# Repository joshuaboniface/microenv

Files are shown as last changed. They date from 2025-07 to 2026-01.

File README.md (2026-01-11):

# MicroEnv v2.x

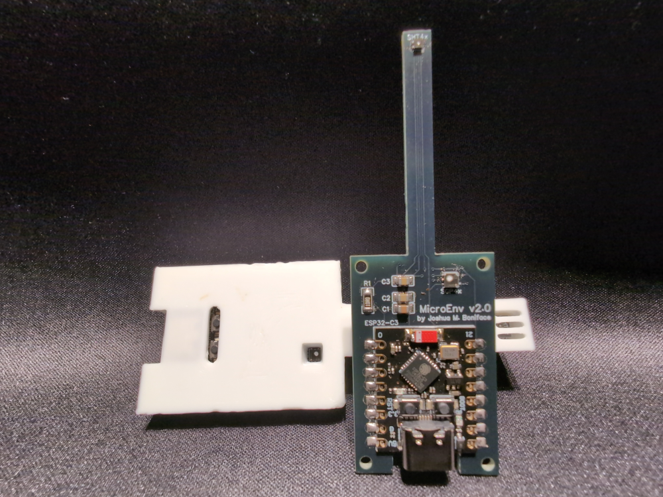
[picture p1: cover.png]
MicroEnv


The MicroEnv is a compact and simplistic environmental monitoring sensor, based on the ESP32-C3 and the Sensirion SGP41 VOC/NOx and SHT45 temperature/humidity sensors, using ESPHome for integration with HomeAssistant.

Use a MicroEnv near a source of emissions to monitor air quality, evaluate temperatures, or as a general room environmental tracking sensor. It is, in effect, a cut down version of the environmental sensor package of my [SuperSensor](https://github.com/joshuaboniface/supersensor) project in a standalone footprint designed for maximum temperature accuracy.

Power is provided by USB-C, which is also used for initial flashing. Once running, the device connects to WiFi to provide data to Home Assistant or via the ESPHome WebUI/API.

The Sensirion sensors are directly soldered onto the board along with their power management circuitry, using SMD techniques, which is in contrast to the socketed GY-form-factor sensors from [version 1.x](https://github.com/joshuaboniface/microenv/tree/v1.x). This provides more compactness and flexibility in terms of positioning to ensure the temperature sensor is properly isolated from the rest of the system.

Version 2.x features an extended 5mm-width, 40mm-length "neck", the end of which contains the SHT45 temperature sensor, for maximum isolation from the ESP32 and SGP41 sensor, both of which produce heat which can negatively affect the SHT45 temperature. This emulates the design of many temperature probe devices which use similar long boards for isolation purposes and work quite well in this regard.

MicroEnv Board Design

The PCB design details and assembly instructions can be found [in /board](board/) and on [OSHWLab](https://oshwlab.com/joshuaboniface/microenv-2-0).

Since this revision uses directly SMD-mounted components, it requires fine soldering using solder paste and either a hotplate or, with extreme care, hot air soldering techniques. It is strongly recommended that anyone attempting to build one read the datasheets for the [SHT45](https://sensirion.com/media/documents/33FD6951/67EB9032/HT_DS_Datasheet_SHT4x_5.pdf) and [SGP41](https://sensirion.com/media/documents/5FE8673C/61E96F50/Sensirion_Gas_Sensors_Datasheet_SGP41.pdf) sensors thoroughly to ensure they are not subject to overheating which can result in potential damage or incorrect operation. We recommend using low-temperature GA-SN solder paste for this purpose, and suggest ordering the PCB with lead-free HASL to facilitate this.

## v1.x Compatibility

The only changes between v1.x and v2.x are in the board layout and component mounting; for software purposes, both versions are functionally identical aside from versioning. Thus all changes should be ported to both the `v1.x` and `v2.x` branches. There is no `master` branch.

## Parts List

**Note:** All prices are $CAD, as of late November 2025, excluding shipping, sales, and bulk discounts beyond those indicated.

**Note:** For AliExpress item links marked `*`, ensure you select the correct device; multiple different models share the page.

| Qty | PCB ID(s) | Component | Cost | Links |
|---|---|---|---|---|
| 1 | N/A | PCB - "MicroEnv" | $0.64 ($3.20/5) | [EasyEDA/JLCPCB](/board/pcb.easyeda.json) |
| 1 | ESP32-C3  | ESP32-C3 development board (SMD) | $2.46 ($12.28/5) | [AliExpress](https://www.aliexpress.com/item/1005007205044247.html)*  |
| 1 | SHT4x | Sensirion SHT45-AD1F-R2 | $9.37 | [DigiKey.ca](https://www.digikey.ca/en/products/detail/sensirion-ag/SHT45-AD1F-R2/17180856) |
| 1 | SGP4x | Sensirion SGP41-D-R4 | $13.00 | [DigiKey.ca](https://www.digikey.ca/en/products/detail/sensirion-ag/SGP41-D-R4/15652788) |
| 1 | R1 | CR1206-FX-10R0ELFCT-ND (10Ω 1% 1/4W 1206) | $0.16 | [DigiKey.ca](https://www.digikey.ca/en/products/detail/bourns-inc/CR1206-FX-10R0ELF/2562695) |
| 1 | C1 | 399-C0805C106K8PACTUCT-ND (10μF 10V X5R 0805)  | $0.19 | [DigiKey.ca](https://www.digikey.ca/en/products/detail/kemet/C0805C106K8PACTU/1090830) |
| 1 | C2 | 399-C0805C104K5RACTUCT-ND (0.1μF 50V X7R 0805) | $0.12 | [DigiKey.ca](https://www.digikey.ca/en/products/detail/kemet/C0805C104K5RACTU/411169) |
| 1 | C3 | 399-C0805C105K3RACTUCT-ND (1μF 50V X7R 0805) | $0.18 | [DigiKey.ca](https://www.digikey.ca/en/products/detail/kemet/C0805C105K3RACTU/2211765) |
| **T** | | | **$26.14** | *plus tools, solder, etc.* |

## Case

The MicroEnv design includes [a case to enclose the sensor](case/) while still providing good airflow to cool the microcontroller and provide quality exposure for the sensors. This case can be printed in any material, though ABS is recommended for rigidity and strength.

## Calibration

Due to its design explicitly focusing on temperature accuracy, the MicroEnv should not require any Temperature Offset corrections in normal use; the option is however still provided just in case this is required in your environment.

The heater component of the SHT45 is explicitly disabled, as this should only be required in extreme humidity conditions.

Like its parent SuperSensor, the MicroEnv provides several additional configurable options for a "Room Health" metric system. For more detail, see [the main SuperSensor README](https://github.com/joshuaboniface/supersensor/tree/v3.x/configuration#room-health) section on the Room Health system.

# Contributing

If you wish to contribute to the MicroEnv project, please open a pull request in this repository. All pull requests will be carefully reviewed before inclusion, as we are extremely selective about what we modify. Note that any signifiant logical changes should also be compatible with the SuperSensor, and changes from that project will be occasionally integrated here.

Please ensure you target the correct branch(es) for your changes. Currently we are supporting both `v1.x` and `v2.x` in software as noted above, and there is no `master`/`main` branch. This support of both `v1.x` and `v2.x` means a 1-to-1 correlation of functionality between those two versions, so any PR to one will be back- or forward-ported to the other, and your changes(s) must be compatable with both.

Any changes must be **globally applicable to all users** of the project; if you wish to maintain your own customizations that are only applicable for yourself, please fork the project and adjust your package import URL accordingly.

"AI" (LLM) contributions are not prohibited, but you - a human - **must** at least review, reformat, and test the changes yourself before submitting them. Obviously pure-LLM-generated PRs that do not function, mangle formatting or functionality, or otherwise clearly have no human review will be rejected with prejudice. This extends to the PR body itself: write in your own words, not the output of an LLM, and if you can't concisely sumarize the changes yourself, then we're not interested in them.

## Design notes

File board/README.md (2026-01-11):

# MicroEnv v2.x Board Designs

This is a collection of [EasyEDA](https://easyeda.com/) schematics and board desgins for the MicroEnv v2.x's components.

You can import the design definition files (`*.easyeda.json`) directly into EasyEDA via "File" -> "Open" -> "EasyEDA". The schematic is provided for reference in both EasyEDA and SVG formats; if you just wish to manufacture the boards, you only need to import the board definitions, then via "Fabrication" -> "One-click Order PCB/SMT" complete the order at [JLCPCB](https://jlcpcb.com). We order all boards in a black silkscreen with all other options as default.

You can also see the designs directly on [OSHWLab here](https://oshwlab.com/joshuaboniface/microenv-2-0).

The board design and images in this folder are © 2026 [Joshua M. Boniface](https://www.boniface.me) and licensed under the [Creative Commons Attribution-ShareAlike (BY-SA) 4.0](LICENSE) license.

## Schematic

The schematic is visible here in SVG format, and also as an EasyEDA definition in [schematic.easyeda.json](schematic.easyeda.json).

Design schematic

The individual parts can be found, with their labels (`R1`, etc.) in the [main README parts list](https://github.com/joshuaboniface/microenv/tree/v2.x?tab=readme-ov-file#parts-list).

## Board

MicroEnv v2.x board

This is the main board of the MicroEnv which contains all components, with the SHT45 sensor on a long (40mm) "neck" to isolate it from the other components.

The board is single-sided; there are no components on the reverse side.

## Assembly

Assembly can be accomplished either by hot-air reflow, or with a hotplate. The instructions are functionally identical for both except for the heating step (#5).

The hot-air process requires the least tools, but is finicky and error-prone. The hotplate process is much simpler and more forgiving, but requires a suitable hotplate. We recommend using the hotplate method for any more than a very small number of MicroEnv sensors.

1. Clean all PCBs thoroughly with isopropyl alcohol and paper towel.

2. Carefully apply solder paste to each pad, with the following guidelines:

   * SHT45/SGP41: A very small amount on each pad, including the center pads; if you think it's not enough, it's just right.
   * Passive SMD components (R1, C1-3): A moderate amount on each pad focusing on the outer edges.
   * ESP32-C3: A very liberal amount on each pad for mechanical stability.

3. Place each component on its corresponding pad using tweezers. Ensure the components are properly aligned and then gently press them down into the solder paste.

   **NOTE**: Placing each component after its corresponding solder paste can avoid accidental smudging.

4. Heat the hot air station to 240C; no higher! Apply heat to the **bottom** of the PCB until all the solder reflows. Check carefully for any bridges or failed joins and gently reflow in the same way as necessary. **Never apply heat directly to the sensors themselves!**

5. Perform electrical continuity tests to ensure there are no stray bridges.

The MicroEnv is now fully assembled and ready for final testing/provisioning.

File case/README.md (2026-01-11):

# MicroEnv v2.x Case

This is a 3D-printable case/enclosure for the MicroEnv v2.0 module. This case optional for functionality, but provides excellent aesthetics and a good mounting point for the sensor.

The design features two individual parts:

* A bottom piece which holds the circuit board.
* A top piece which covers the circuit board and sensors, with ample clearance for the components, a USB cable, and airflow for the sensors.

You can [tinker the design on TinkerCAD here](https://www.tinkercad.com/things/irFmvsATUlu-microenv-sensor-v2x-case).

The case design and images in this folder are © 2026 [Joshua M. Boniface](https://www.boniface.me) and licensed under the [Creative Commons Attribution-ShareAlike (BY-SA) 4.0](LICENSE) license.

## Printing

In this directory are 2 `.obj`-format CAD files providing the case. They should be compatible as-is with any slicing software and 3D printer model; no rotation or other transformations are required.

As a general set of parameters, all models should be printed with the following. All values are provided as their OrcaSlicer 2.3 names; your slicer may differ.

* 0.4mm nozzle/line width (or similar as provided by the slicer)
* 0.16mm layer height, or a clean multiple thereof
* No brim or raft
* 7-10 wall loops
* 7-10 shell layers (top + bottom)
* 25% infill
* Concentric patterns for infill
* Concentric patterns for surfaces (visual only)
* Back (preferred) or Aligned seams (visual only)

All other options are be specific to your printer, material, and desired effect.

The parts should be printed in a solid, durable material of any colour you wish. We use ABS in one of two colours (black or white) for our official prints.

### Case Models

These are the models that make up the case. Each case requires 1x `case-bottom` and 1x `case-top`.

#### `case-bottom`

This is the lower section of the case which directly holds the PCB and includes the male mating inserts. It also includes 3 vents for the SHT45.

#### `case-top`

This is the upper section of the case which covers the PCB and includes the female mating indents. It includes a pyramidal opening for the SGP41 sensor, 3 top and 4 side vents for the SHT45, and several cutouts for the USB connection.

## Assembly & Installation

To begin, print the parts above as required for the specific mounting type you want.

1. Insert the PCB into the `case-bottom` print, ensuring that the holes in the PCB align with the standoffs in the print. There may be some play due to board or case warping, so press it down as far as it will go.

2. Take the `case-top` print, and align the male/female mating components, ensuring that the SGP41 sensor is correctly centered within it opening.

3. Press down gently but firmly on a hard even surface to combine the mating components and close the case.

**NOTE**: Once mated, the two prints can not be easily separated without likely damaging the male mating inserts. If you must open the case again, you may need to re-print the `case-bottom` model.

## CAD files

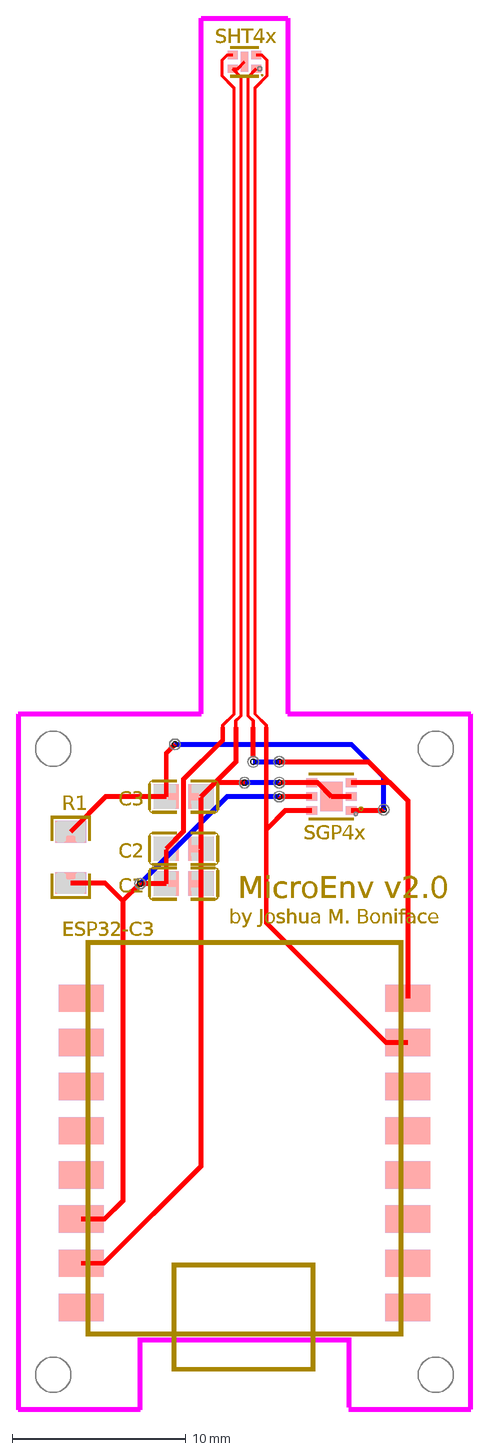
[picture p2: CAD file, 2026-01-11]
board/board.dxf
MicroEnv v2.0
by Joshua M. Boniface
SGP4x
ESP32-C3
SHT4x
R1
C1
C2
C3

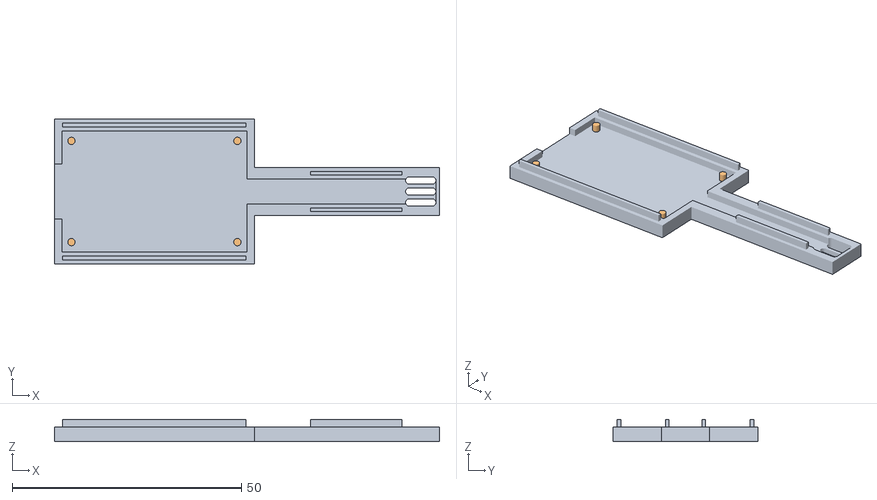
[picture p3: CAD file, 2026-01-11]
case/case-bottom.obj
84.0 x 31.6 x 4.80

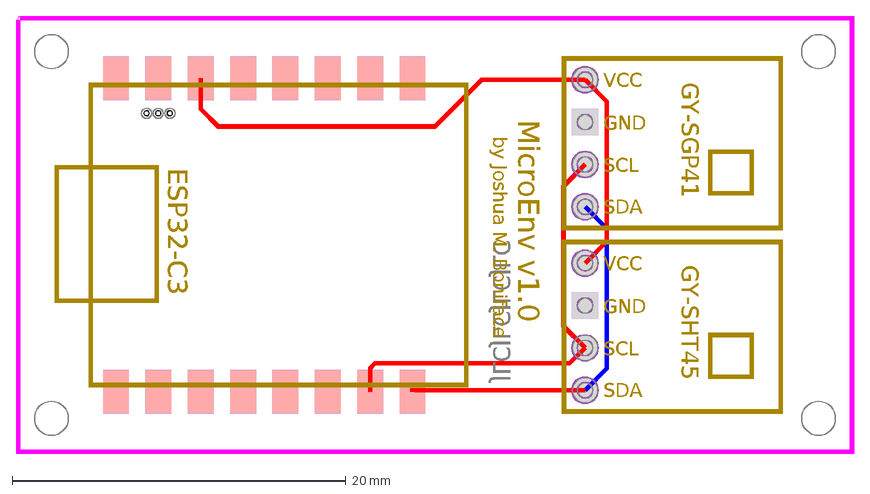
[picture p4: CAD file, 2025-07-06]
board/pcb.dxf
JLCJLCJLCJLC
MicroEnv v1.0
by Joshua M. Boniface
ESP32-C3
GY-SGP41
VCC
GND
SCL
SDA
GY-SHT45

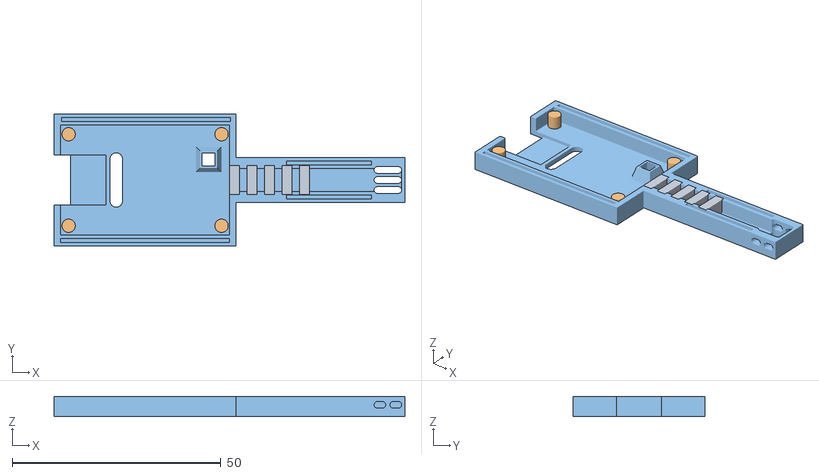
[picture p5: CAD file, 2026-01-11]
case/case-top.obj
84.0 x 31.6 x 4.80

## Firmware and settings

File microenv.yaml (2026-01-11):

---

###############################################################################
# MicroEnv v2.0 ESPHome configuration
###############################################################################
#
#    Copyright (C) 2025 Joshua M. Boniface <joshua@boniface.me>
#
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
###############################################################################

esphome:
  name: microenv
  name_add_mac_suffix: true
  friendly_name: "MicroEnv Sensor"
  project:
    name: "Joshua Boniface.microenv"
    version: "2.0"
  min_version: 2025.11.0

dashboard_import:
  package_import_url: github://joshuaboniface/microenv/microenv.yaml@v2.x

esp32:
  board: esp32-c3-devkitm-1
  variant: esp32c3
  framework:
    type: esp-idf

preferences:
  flash_write_interval: 15sec

globals:
  - id: temperature_offset
    type: float
    restore_value: true
    initial_value: "0.0"

  - id: humidity_offset
    type: float
    restore_value: true
    initial_value: "0.0"

  #
  # Room Health settings
  #
  - id: room_health_temperature_min
    type: float
    restore_value: true
    initial_value: "21.0"

  - id: room_health_temperature_max
    type: float
    restore_value: true
    initial_value: "24.0"

  - id: room_health_temperature_penalty
    type: float
    restore_value: true
    initial_value: "10.0"

  - id: room_health_humidity_min
    type: float
    restore_value: true
    initial_value: "40.0"

  - id: room_health_humidity_max
    type: float
    restore_value: true
    initial_value: "60.0"

  - id: room_health_humidity_penalty
    type: float
    restore_value: true
    initial_value: "5.0"

  - id: room_health_voc_weight
    type: float
    restore_value: true
    initial_value: "0.4"

  - id: room_health_temperature_weight
    type: float
    restore_value: true
    initial_value: "0.3"

  - id: room_health_humidity_weight
    type: float
    restore_value: true
    initial_value: "0.3"

logger:
  level: DEBUG
  baud_rate: 115200

api:
  reboot_timeout: 15min

ota:
  platform: esphome

web_server:
  port: 80

captive_portal:

mdns:
  disabled: false

wifi:
  ap: {}
  domain: ""
  output_power: 8.5dB
  reboot_timeout: 15min
  power_save_mode: none

i2c:
  - id: i2c_bus
    sda: GPIO21
    scl: GPIO20
    scan: true

sensor:
  - platform: sgp4x
    voc:
      name: "SGP41 VOC Index"
      id: sgp41_voc_index
      accuracy_decimals: 0
      icon: mdi:waves-arrow-up
      filters:
        - sliding_window_moving_average:          # We take a reading every 5 seconds, but calculate the sliding
            window_size: 12                       # average over 12 readings i.e. 60 seconds/1 minute to normalize
            send_every: 3                         # brief spikes while still sending a value every 15 seconds.
    nox:
      name: "SGP41 NOx Index"
      id: sgp41_nox_index
      accuracy_decimals: 0
      icon: mdi:waves-arrow-up
      filters:
        - sliding_window_moving_average:
            window_size: 12
            send_every: 3
    compensation:
      temperature_source: sht45_temperature
      humidity_source: sht45_humidity
    store_baseline: true
    update_interval: 5s

  - platform: template
    name: "SGP41 TVOC (µg/m³)"
    id: sgp41_tvoc_ugm3
    icon: mdi:molecule
    lambda: |-
      float i = id(sgp41_voc_index).state;
      if (i < 1) return NAN;
      float tvoc = (log(501.0 - i) - 6.24) * -878.53;
      return tvoc;
    unit_of_measurement: "µg/m³"
    accuracy_decimals: 0
    update_interval: 15s

  - platform: template
    name: "SGP41 TVOC (ppb)"
    id: sgp41_tvoc_ppb
    icon: mdi:molecule
    lambda: |-
      float tvoc_ugm3 = id(sgp41_tvoc_ugm3).state;
      float tvoc_ppm = tvoc_ugm3 * 0.436;  // ppb estimated using isobutylene MW (56.1 g/mol)
      return tvoc_ppm;
    unit_of_measurement: "ppb"
    accuracy_decimals: 0
    update_interval: 15s

  - platform: template
    name: "SGP41 eCO2 (appr.)"
    id: sgp41_eco2_appr
    icon: mdi:molecule-co2
    lambda: |-
      float tvoc_ppb = id(sgp41_tvoc_ppb).state;
      float eco2_ppm = 400.0 + 1.5 * tvoc_ppb;
      if (eco2_ppm > 2000) eco2_ppm = 2000;
      return eco2_ppm;
    unit_of_measurement: "ppm"
    accuracy_decimals: 0
    update_interval: 15s

  - platform: sht4x
    temperature:
      name: "SHT45 Temperature"
      id: sht45_temperature
      accuracy_decimals: 1
      filters:
        - offset: !lambda return id(temperature_offset);
        - sliding_window_moving_average:
            window_size: 4
            send_every: 1
    humidity:
      name: "SHT45 Relative Humidity"
      id: sht45_humidity
      accuracy_decimals: 1
      filters:
        - lambda: |-
            // Grab measured and corrected temperatures
            float t_meas = id(sht45_temperature).state - id(temperature_offset);
            float t_corr = id(sht45_temperature).state;
            float rh_meas = x;
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

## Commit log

2025-05-28 Add textual environmental sensors
2025-06-21 Convert to SGP41 sensor
    SGP30's were too unreliable, so swap to the SGP41 and its adjusted
    configurations. We leverage the same algorithm and values as the
    AirGradient One to ensure consistency.
    [microenv.yaml]
2025-07-06 Fix name of the eCO2 sensor
    [microenv.yaml]
2025-07-06 Update README with recent updates and add board
    [pcb.dxf]
2025-07-17 Set update intervals for template sensors
2026-01-11 Update config, README, board, case for v2.x
    [board.dxf, case-bottom.obj, case-top.obj]
2026-01-17 Add board license

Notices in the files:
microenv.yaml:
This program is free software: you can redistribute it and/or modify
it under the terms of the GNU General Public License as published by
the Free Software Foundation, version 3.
